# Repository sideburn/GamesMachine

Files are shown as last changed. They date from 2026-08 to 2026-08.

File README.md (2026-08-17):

# Games Machine

KiCad recreation of **"Games Machine — a programmed random number generator"** by D. Burn,
*Practical Electronics*, December 1976 (pp. 969–975). PCB by Sideburn Studios.

A TTL-logic random number generator with four selectable modes:

| Mode | Range | Zero behaviour |
|---|---|---|
| Random | 0–99 | `00` allowed |
| Roulette | 0–36 | `00` allowed |
| Pools | 1–59 | single zero allowed, `00` blocked |
| Dice | 1–6 per digit | no zero in either digit |

Randomness comes from an avalanche-noise transistor (TR1) feeding a two-stage amplifier
(TR2, TR3), squared by a 7413 Schmitt trigger, and gated into a pair of 7490 decade counters
while a 2N2646 UJT relaxation oscillator (TR4) free-runs at 3–4 s. Because the operator's
press and the oscillator phase are uncorrelated, the stopping point is unpredictable. Game
ranges and the zero-detector restart logic come from a diode-resistor matrix (D5–D20) read
through an interlocked pushbutton bank (S1, S3–S6).

## Status

**Rev 1.0** — fabricated 2026-07-09, built and fully bench-tested. All four game modes verified
working against the behaviour described in the original article. Three defects were found and
worked around on the physical board (see below).

**Rev 2.0** — all fixes applied to the KiCad source, DRC clean (0 violations, 0 unconnected),
gerbers and drill files regenerated. Ready to order; not yet fabricated.

### Fixes applied for rev 2.0

| # | Issue | Resolution |
|---|---|---|
| 1 | `LOGIC_0` was a floating net, never tied to ground — board freezes at `99` | Merged into `GND` |
| 2 | Diode silkscreen band marked the anode, so all 17 diodes fitted backwards to the print | Symbol pin numbers swapped, diodes rotated 180° |
| 3 | UNITS/TENS displays placed in reverse reading order — digits read transposed | Placements exchanged |
| 4 | 2N2926 symbol declared E-B-C; the real part is E-C-B, so TR1–TR3 needed crossed leads | Pin numbers corrected |
| 5 | TR4 (2N2646) footprint mapping suspected wrong | Verified correct as drawn — no change |

Full detail, including what was deliberately left alone, is in `Docs/Rev2_Board_Fixes.md`.

## Notes for anyone building one

- **Identify a UJT's leads by measurement, never from a pinout diagram.** Ohms-mode resistive
  pair = the two bases, the leftover lead = emitter; the can-to-lead short then separates B1
  from B2. Two of the three 2N2646s sourced for this build were counterfeit or dead, and one
  passed a static meter test while being unable to fire under real operating bias.
- TR4 wants rotating roughly 10° clockwise of the silkscreen tab mark when fitting — the TO-18
  leads sit on a circle and don't land dead-on the pad angles.

## Repository contents

- `GamesMachine.kicad_sch` / `.kicad_pcb` / `.kicad_pro` — the KiCad project
- `GamesMachine.kicad_sym` — project-local symbol library (custom parts)
- `GamesMachine.stl` — 3D case/board model
- `Gerbers/` — fabrication output, regenerated for rev 2.0
- `Docs/PartsList.md` — full parts list with sourcing notes
- `Docs/BOM.csv` — machine-readable BOM exported from the schematic
- `Docs/BringUp_TestPlan.md` — staged bring-up and test procedure
- `Docs/GameMode_Jumper_Reference.md` — switch/jumper configuration per game mode
- `Docs/Rev2_Board_Fixes.md` — defect record and how each was resolved

The first commit is the rev 1.0 project exactly as fabricated, so the whole set of fixes can be
read as a diff against the board that was actually built.

## Original source

*Practical Electronics*, Vol. 12 No. 12, December 1976. Article by D. Burn, PhD.
The magazine scan is not redistributed here.

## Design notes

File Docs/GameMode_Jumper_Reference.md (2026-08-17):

# Games Machine — Game Mode Jumper Reference

Bench-test jumper configurations for each game mode, confirmed working 2026-08-17. These
simulate the real interlocked pushbutton switches (S3-S6) until the physical switch loom is
wired in.

General pattern for every S3/S4/S5/S6 pole: pin 1 = input from previous switch in the chain,
pin 2 = "released" (pass-through to next switch), pin 3 = "pressed" (this mode's own decode
network or ground). Only one mode's switch should be "pressed" (1&3) at a time — everything
else stays in pass-through (1&2) or fully open, matching the real hardware's mechanical
interlock (pressing one button releases whichever was previously pressed).

S1 (Play) is a separate 2-pole momentary button, not part of this chain — pressed = pin 1&2
connected.

**On "all others open" below:** with real physical switches, no pole is ever truly
disconnected — every unpressed switch mechanically rests at 1&2 (released), every pressed
one sits at 1&3. "Open" in the tables below is a bench-jumper shortcut for switches outside
the active chain for that mode; jumpering them to 1&2 instead is equally correct and in fact
more accurately mirrors how the finished hardware behaves.

---

## Random — range 0–99

| Switch | Position |
|---|---|
| S3a, S3b | 1&3 closed |
| S5c, S6d | 1&2 closed |

All others open.

## Roulette — range 0–36

| Switch | Position |
|---|---|
| S3a, S3b | 1&2 closed |
| S4a, S4b | 1&3 closed |
| S5c | 1&2 closed |
| S6d | 1&2 closed |

All others open.

## Pools — range 1–59

| Switch | Position |
|---|---|
| S3a, S3b | 1&2 |
| S4a, S4b | 1&2 |
| S5a, S5b, S5c | 1&3 |
| S6c | 1&2 |

All others open.

## Dice — 1–6 each digit

| Switch | Position |
|---|---|
| S3a, S3b | 1&2 |
| S4a, S4b | 1&2 |
| S5a, S5b, S5c | 1&2 |
| S6a, S6b, S6c, S6d | 1&3 |

---

## Zero-digit behavior by mode

- **Random**: 00 fully allowed (confirmed stable, non-blanking stop).
- **Roulette**: 00 fully allowed (per article: "a selection of 00 is perfectly acceptable").
- **Pools**: single zero in either digit allowed (e.g. 02, 20); double-zero (00) blocked,
  triggers blank-and-respin.
- **Dice**: no zero allowed in either digit — cannot stop while either digit shows 0.

Source: original article, *Practical Electronics*, Dec 1976, "Random Number Gamesmachine"
by D. Burn, p.972 (Zero Detector section) and p.971-972 (circuit description).

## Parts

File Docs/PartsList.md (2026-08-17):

# Games Machine — parts list

Generated from the rev 2.0 schematic. Quantities are for one board.

Resistors are ¼ W carbon film throughout; the footprints are 10.16 mm pitch axial.

## On-board parts

### Resistors

| Refs | Value | Qty | Function |
|---|---|---|---|
| R1 | 47 kΩ | 1 | Noise generator, TR1 emitter feed |
| R2 | 4.7 kΩ | 1 | TR2 collector load |
| R3 | 100 kΩ | 1 | TR3 collector-base bias |
| R4, R5 | 2.2 kΩ | 2 | TR3 collector load, noise output |
| R6 | 150 kΩ | 1 | UJT clock timing (with C4) |
| R7 | 220 Ω | 1 | UJT clock output |
| R8, R9, R10 | 4.7 kΩ | 3 | Open-collector pull-ups for IC11 |
| R11–R24 | 270 Ω | 14 | Display segment current limiting |
| R25 | 1 kΩ | 1 | `LOGIC_1` pull-up |
| R26–R30 | 1 kΩ | 5 | Game-mode decode pull-ups |

### Capacitors

| Refs | Value | Qty | Notes |
|---|---|---|---|
| C1, C2, C4 | 10 µF | 3 | Article specifies 16 V tantalum; modern electrolytics work fine. Polarity: **+ toward the higher-voltage node** |
| C3 | 0.1 µF | 1 | Ceramic disc |

### Semiconductors

| Refs | Part | Qty | Notes |
|---|---|---|---|
| TR1–TR3 | 2N2926 | 3 | Noise generator. Real pinout is **E-C-B** |
| TR4 | 2N2646 | 1 | UJT clock oscillator. Article also allows TIS43 |
| D5–D20 | 1N914 | 16 | Game-mode decode matrix |
| Z1 | 1N4733A (5.1 V) | 1 | Rail clamp |
| IC1 | 7413 | 1 | Dual 4-input Schmitt NAND — squares the noise, gates it |
| IC2 | 7472 | 1 | JK flip-flop — start/stop bistable |
| IC3, IC4 | 7490 | 2 | Decade counters (tens, units) |
| IC5, IC6 | 7447 | 2 | BCD to 7-segment decoders |
| IC9 | 7425 | 1 | Dual 4-input NOR — zero detector |
| IC10 | 7480 | 1 | Gated full adder, used as switchable AND/OR |
| IC11 | 7412 | 1 | Triple 3-input open-collector NAND — restart logic |

### Connectors and other

| Refs | Part | Qty | Notes |
|---|---|---|---|
| PWR1 | JST PH 3-pin vertical | 1 | +17 V, +5 V, GND from the supply |
| S1 | JST PH 2-pin vertical | 1 | Play button |
| S3a–S6d | JST PH 3-pin vertical | 11 | Game-mode switch bank, one per pole |
| F1 | 0.5 A resettable PTC | 1 | Radial, 5 mm |
| TENS1, UNITS1 | 14-pin DIP socket | 2 | The DL707 displays plug in here |

IC sockets are strongly recommended for all of IC1–IC11 — most of these are obsolete parts and
you'll want to be able to swap them while testing.

## Off-board parts

| Part | Qty | Notes |
|---|---|---|
| DL707 7-segment display, common anode | 2 | 0.3 in red. Plug into TENS1/UNITS1 |
| Interlocked pushbutton bank | 1 | 5 latching buttons plus one Play. Article used a Doram 8-switch frame with latching bar and return spring; pressing one button releases the others |
| Power supply | 1 | +17 V and +5 V. See below |

### Power

The article's own supply (its Fig. 3) is a mains transformer, bridge rectifier, 2200 µF filter
and a µA7805 regulator, giving ~17 V unregulated plus a regulated 5 V rail. None of that lives
on this board — it arrives through PWR1.

The simplest modern equivalent is a single regulated **18 V, 1 A universal-input (100–240 V)
switching adapter**, with the 5 V rail derived from it. Typical measured draw is around 120 mA
on the 5 V rail with everything populated.

## Sourcing notes

Most of the logic is obsolete but still easy to find from surplus dealers. Two parts deserve
attention.

**2N2646 (TR4)** — this is the part most likely to waste your time. Of three obtained for this
build, one was a relabelled PNP bipolar (not a UJT at all), one was genuine but so degraded by
age that it passed every static meter test while being unable to fire under real operating bias,
and one was good. Buy from a dealer with verifiable vintage stock, buy spares, and **test each
one before fitting**:

1. Ohms mode: the two leads showing a resistive 4.7–9 kΩ both ways are the bases; the leftover
   lead is the emitter.
2. The base that reads ~0 Ω to the metal can is B2.
3. Diode mode from the emitter: a normal forward drop into each base, open in reverse.

A genuine part that passes this can still be too aged to oscillate, so the real test is fitting
it and looking for the sawtooth at the emitter. **2N6027** programmable UJTs are still in
production and can substitute, but need a gate-bias divider added and R6 changed to ~330 kΩ.

**2N2926 (TR1–TR3)** — real pinout is **E-C-B**, which trips up a lot of pinout diagrams online.
Rev 2.0 of this board is drawn for the correct order, so parts drop straight in.

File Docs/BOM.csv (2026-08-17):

Refs | Value | Footprint | Qty
C1,C2,C4 | 10uF | Capacitor_THT:CP_Radial_D5.0mm_P2.50mm | 3
C3 | 0.1uF | Capacitor_THT:C_Disc_D5.0mm_W2.5mm_P2.50mm | 1
D5-D20 | 1N914 | Diode_THT:D_DO-35_SOD27_P7.62mm_Horizontal | 16
F1 | PTC_0.5A | Capacitor_THT:C_Disc_D5.0mm_W2.5mm_P5.00mm | 1
IC1 | 7413 | Package_DIP:DIP-14_W7.62mm | 1
IC2 | 7472 | Package_DIP:DIP-14_W7.62mm | 1
IC3,IC4 | 7490 | Package_DIP:DIP-14_W7.62mm | 2
IC5,IC6 | 7447 | Package_DIP:DIP-16_W7.62mm | 2
IC9 | 7425 | Package_DIP:DIP-14_W7.62mm | 1
IC10 | 7480 | Package_DIP:DIP-14_W7.62mm | 1
IC11 | 7412 | Package_DIP:DIP-14_W7.62mm | 1
PWR1 | POWER_JST_PH3 | Connector_JST:JST_PH_B3B-PH-K_1x03_P2.00mm_Vertical | 1
R1 | 47k | Resistor_THT:R_Axial_DIN0207_L6.3mm_D2.5mm_P10.16mm_Horizontal | 1
R2,R8-R10 | 4.7k | Resistor_THT:R_Axial_DIN0207_L6.3mm_D2.5mm_P10.16mm_Horizontal | 4
R3 | 100k | Resistor_THT:R_Axial_DIN0207_L6.3mm_D2.5mm_P10.16mm_Horizontal | 1
R4,R5 | 2.2k | Resistor_THT:R_Axial_DIN0207_L6.3mm_D2.5mm_P10.16mm_Horizontal | 2
R6 | 150k | Resistor_THT:R_Axial_DIN0207_L6.3mm_D2.5mm_P10.16mm_Horizontal | 1
R7 | 220 | Resistor_THT:R_Axial_DIN0207_L6.3mm_D2.5mm_P10.16mm_Horizontal | 1
R11-R24 | 270 | Resistor_THT:R_Axial_DIN0207_L6.3mm_D2.5mm_P10.16mm_Horizontal | 14
R25-R30 | 1k | Resistor_THT:R_Axial_DIN0207_L6.3mm_D2.5mm_P10.16mm_Horizontal | 6
S1 | SPDT | Connector_JST:JST_PH_B2B-PH-K_1x02_P2.00mm_Vertical | 1
S3a1,S3b1,S4a1,S4b1,S5a1,S5b1,S5c1,S6a1,S6b1,S6c1,S6d1 | SPDT | Connector_JST:JST_PH_B3B-PH-K_1x03_P2.00mm_Vertical | 11
TENS1 | TENS_DISP_SOCKET | Package_DIP:DIP-14_W7.62mm | 1
TR1-TR3 | 2N2926 | Package_TO_SOT_THT:TO-92_Inline | 3
TR4 | 2N2646 | Package_TO_SOT_THT:TO-18-3 | 1
UNITS1 | UNITS_DISP_SOCKET | Package_DIP:DIP-14_W7.62mm | 1
Z1 | 1N4733A_5.1V | Diode_THT:D_DO-41_SOD81_P10.16mm_Horizontal | 1

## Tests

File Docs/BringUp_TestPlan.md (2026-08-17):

# Games Machine — Board Bring-Up & Sectional Test Plan

Random Numbers Game Machine, Sideburn Studios
Source design: "Games Machine — a programmed random number generator", D. Burn,
*Practical Electronics*, December 1976, pp. 969–975.

Published reference copy: https://claude.ai/code/artifact/c53d6dda-828d-4b43-869a-0b2889a355c7

---

> ## ⚠ Check your board revision first
>
> This plan was written against **rev 1.0**. The two workarounds under "Before you assemble"
> apply **only to rev 1.0** — both defects are fixed in the rev 2.0 design.
>
> **On a rev 2.0 board, skip findings 1 and 2 entirely:**
> - Do **not** fit the `LOGIC_0` → ground bodge wire. That net is part of `GND` now.
> - Do **not** fit the diodes opposite the silkscreen. The band marks the **cathode** correctly
>   on rev 2.0, so "backwards to the print" would put all 17 diodes in the wrong way round.
>
> Everything from "Staged bring-up" onward applies to both revisions — the circuit itself is
> unchanged. The schematic title block gives the revision.

---

## Before you assemble — three findings *(rev 1.0 only — see warning above)*

### 1. CRITICAL — `LOGIC_0` is never connected to ground *(rev 1.0 only)*

`GND` and `LOGIC_0` are two separate nets on this board. In the 1976 schematic the "0" symbol
simply *is* 0 V, but here `LOGIC_0` was drawn as its own label and never tied down. It has
38 routed track segments and 12 pads, and **no source of any kind** — no connector pin, no
resistor, no link to the ground pour.

Pads on `LOGIC_0`: IC2 pins 3, 4, 5 (J1–J3) · IC3 pins 6, 7 · IC4 pins 6, 7 (set-to-nine) ·
S3a pin 3 · S3b pin 3 · S5a pin 3 · S6c pin 2 · S6d pin 2.

Floating TTL inputs read as logic 1, so as built:

- Both 7490s permanently forced to nine → frozen `99` on the display, never counts.
- IC2 J-inputs high → the bistable toggles instead of resetting; start/stop unreliable.
- Random and pools switch positions cannot release the counter resets.

**Fix:** one short insulated wire on the solder side, **IC3 pin 7 → IC3 pin 10**. That is one
`LOGIC_0` pad to one `GND` pad on the same package. Afterwards confirm continuity at a far
point such as IC2 pin 3. Correct the schematic before any future board order.

### 2. Diode silkscreen band is on the anode end

The project's cached `Device:D` symbol has **pin 1 = anode, pin 2 = cathode**. Stock KiCad has
it the other way round, and the stock THT diode footprints put the printed cathode band at the
**pad 1** end. So the silk band sits at the end the netlist treats as the anode — on all
sixteen 1N914s and on Z1.

The netlist intent is electrically correct (diode-AND gates with anode on the pulled-up node;
Z1 cathode to +5V). Only the printed marking misleads.

**Verify on the bare board:** the Z1 pad at the silkscreen band end should show continuity to
`GND`, the far pad to `+5V`. If so, fit every diode with its **body band pointing away from the
printed band**. Z1 backwards puts a forward diode across the 5 V rail.

### 3. No decoupling, and a tight fuse

- **No supply decoupling anywhere on the digital section.** C1–C4 all belong to the analogue
  block. Add 100 nF ceramic across pins 7/14 of each DIP (8/16 on the 7447s) and a 100 µF bulk
  cap at `PWR`. Much easier during assembly than after.
- **F1** is a 0.5 A PTC in series with the whole 5 V rail; worst-case draw is near 600 mA.
- **Z1** is a 1N4733A 5.1 V zener directly across a 5.0 V rail — close enough to its knee to
  conduct continuously. Consider a 1N4734A (5.6 V) or omit.

---

## Bench setup

`PWR` is a 3-pin JST PH at the right-hand edge. No on-board regulator — both rails come in
externally.

| Pin | Net | Set to | Current limit | Feeds |
|-----|-----|---|---|---|
| 1 | GND | 0 V common | — | Ground pour, all IC ground pins |
| 2 | +5V_IN | 5.00 V | start 100 mA | Through F1 to all logic and both displays |
| 3 | +17V | 17.0 V | 50 mA | Only R2, R4, R6, TR4 — analogue section |

**Sequencing:** bring 5 V up first, then *ramp* 17 V. Power 17 V down first, 5 V last. The
noise output couples through C3 (0.1 µF) straight onto IC1 pin 5, a TTL input with no positive
clamp; switching 17 V in abruptly couples that step into the input.

If the supply's outputs are independent, tie both negatives together at the board.

**Two changes worth making for bench work:**

- Link out F1 and let the bench current limit protect instead — faster, adjustable, and it
  removes the PTC volt-drop from rail measurements.
- Socket every IC. The whole plan depends on populating the board progressively.

---

## Stages

Ordered so each stage only powers what the previous one proved. The display end is proved first
and you work backwards toward the analogue front end.

### Stage 0 — Bare board, before soldering

| Check | Probe | Expect | Meaning |
|---|---|---|---|
| Ground integrity | PWR pin 1 → IC1 pin 7, IC5 pin 8 | < 1 Ω | Pour reaches every package |
| **LOGIC_0 defect** | IC3 pin 7 → PWR pin 1 | **OPEN** | Confirms the defect |
| LOGIC_1 rail | IC1 pin 1 → R25 pad 2 | < 1 Ω | Tie-high net routed |
| Rail short | +5V pad → GND | open | No fabrication short |
| **Diode marking** | Z1 band-end pad → GND | continuity | Band is on the anode — fit diodes reversed to print |
| 17 V rail | PWR pin 3 → R2, R4, R6 | < 1 Ω | Routed, and isolated from +5V |

### Stage 1 — Power section and the ground fix

Fit: PWR, F1 (or link), Z1, R25, the LOGIC_0 wire link, all IC sockets, decoupling caps.
Leave every socket **empty**. 5.00 V, limit 100 mA.

| Measure | Expect | If it differs |
|---|---|---|
| Total 5 V current | < 5 mA | Tens of mA → Z1 conducting; swap for 1N4734A or omit |
| Rail at each socket Vcc | 5.00 V | Sag points at F1 or a routing fault |
| LOGIC_1 at IC1 pin 1 | ≈ 5.0 V | 0 V → R25 open or misfitted |
| LOGIC_0 at IC2 pin 3 | 0.00 V | Link did not take, or net not fully routed |
| Z1 temperature | cold | Warm → continuous conduction |

**Stop if** 5 V current exceeds a few mA with no ICs fitted.

### Stage 2 — The 17 V rail

Sockets still empty. With 5 V already up, **ramp** the second output slowly to 17 V, limit
50 mA. Confirm 17 V at the top of R2, R4, R6, and **0 V at IC1 pin 5** (held down by R5).

### Stage 3 — Noise generator and clock

Fit: TR1–TR3, TR4, R1–R7, C1–C4. Logic sockets still empty.

Orientation notes:
- TR1–TR3 = 2N2926, TO-92, pad 1 = E, 2 = B, 3 = C.
- TR4 = 2N2646 UJT in **TO-18 metal can** (different footprint), pad 1 = E, 2 = B1, 3 = B2.
- C1, C2, C4 are correctly silk-marked (unlike the diodes): **+** is the pad 1 end.
- **TR1's collector is deliberately unconnected.** The noise comes from its reverse-biased
  base-emitter junction avalanching. Do not "fix" it.

| Test | Where | Pass criterion |
|---|---|---|
| Clock running | across R7 (220 Ω) | A pulse every ~3–4 s, visible on a DMM |
| Noise present | NOISE_OUT / IC1 pin 5 | Random noise you **cannot trigger the timebase on**. A stable trace means the noise source is *not* working. |
| DC sanity | NOISE_OUT to GND | Low DC level (R5 holds it down). Near 17 V → C3 leaky or misfitted. |

No noise usually means this particular 2N2926 will not avalanche at 17 V — breakdown scatters
between devices. Try another transistor.

**Stop if** NOISE_OUT sits at a high DC level — fitting IC1 with 17 V on a TTL input destroys it.

### Stage 4 — Displays and decoders, via the lamp test

Fit: IC5, IC6, R11–R24, both DL707s. **5 V only, 17 V off.** Raise the 5 V limit to ~700 mA.

The 7447 lamp-test input is on **pin 3** of both decoders. **Ground pin 3 and every segment
lights**, showing `8`. That verifies the decoder, all seven segment resistors, the socket wiring
and the display itself, per digit, with no counter or clock involved.

With both digits showing `8` you are at worst-case display current — **this is also your F1
margin measurement**. Note the total.

Blanking (pin 4 on both 7447s) comes from IC2, which is not fitted, so it floats high and
blanking is inactive. Tack a temporary 1 kΩ from that net to +5 V so it is held rather than
floating.

Displays are confirmed **DL707 / MB101 common anode**; the board correctly ties socket pins 3
and 14 to +5 V. Socket pin 9 (third common anode) is unconnected — harmless, but strapping it
to pin 3 shares segment current across three pins instead of two.

### Stage 5 — Counters, on an injected clock

Fit: IC3, IC4, IC11, R8–R10.

With no switch panel wired the reset lines float high and hold both counters cleared (`00`).
To emulate **random numbers** mode on the bench, ground **S3a pin 1** and **S3b pin 1**
(the `IC4_R0` and `IC3_R0` connector pins). Both counters can then run 0–99.

Inject **1–2 Hz** at **IC4 pin 14** (units counter clock). A debounced pushbutton works for
single-stepping.

**Expect a strange counting sequence — it is correct.** The tens digit is clocked from the
units **C** output inverted by IC11c, so the tens digit advances each time the units digit
passes 4. The article does this deliberately: in dice mode the units counter resets at 6, so D
never toggles and a conventional carry would never fire. No numbers are lost.

**Stop if** you see a frozen `99` — that is the signature of the `LOGIC_0` defect.

### Stage 6 — Gate and bistable

Fit: IC1, IC2.

Keep the UJT clock out of circuit so you can step by hand: **lift R7**, fit a temporary 1 kΩ
from IC1 pin 9 to +5 V, and a momentary pushbutton from pin 9 to ground. Press-and-release
generates the falling edge that clocks IC2. Keep injecting the slow clock at IC4 pin 14.

**The net names lie — the wiring is right.** The custom 7472 symbol has its labels swapped
against the real SN7472 (clear on pin 2, preset on pin 13, Q on pin 8, Q̄ on pin 6). Both pairs
are inverted, so they cancel and the board is wired exactly as the article specifies. But the
net named `IC2_Q` is physically Q̄, and `IC2_QBAR` is physically Q.

| Action | Expect | Because |
|---|---|---|
| At rest | Display lit and static | Q̄ high, blanking inactive; gate closed |
| Press Play (S1 pin 1 to ground) | Display **blanks**, counting starts | Preset asserted: Q high opens the gate, Q̄ low blanks the 7447s |
| Release Play, pulse manual clock | Counting stops, number appears | J=0, K=1 resets on the clock edge |

Then restore R7 and let the real 3–4 s UJT clock take over.

### Stage 7 — Game modes and zero detector

Fit: D5–D20, R26–R30, IC9, IC10, the switch loom. Keep the injected slow clock.

| Mode | Range | Expected behaviour |
|---|---|---|
| **No game selected** | — | Holds `00`, will not count. Designed behaviour; confirm first. |
| Random | 00–99 | Full cycle in the odd sequence; stoppable on any count including `00` |
| Roulette | 0–36 | Reaches 33 via `36 30 31 32`, resets to `04`, continues `05 06 07`… |
| Pools | 1–59 | `…58 59 50 51 52 53 04 05…`. Stops on a single zero, **ignores stop when both digits are zero** |
| Dice | 1–6 each | Neither digit exceeds 6; **cannot be stopped while either digit shows zero** |

The last two rows are the zero detector working: IC9 spots an all-zero digit, IC10 combines the
two digits as AND or OR depending on S6c, IC11b restarts the count.

Finally remove every temporary link — blanking pull-up, manual clock switch, grounded reset
pins, injected clock.

---

## Reference

### Current budget (approximate, typical standard TTL)

| Load | Typical | Note |
|---|---|---|
| Nine TTL packages | ≈ 290 mA | The two 7447s dominate at ~64 mA each |
| Both digits showing `88` | ≈ 155 mA | 14 segments × ~11 mA through 270 Ω |
| Typical running total | ≈ 400 mA | Average digit lights about five segments |
| **Worst case** | **≈ 580 mA** | Past F1's 0.5 A hold current |
| 17 V rail | < 15 mA | Only R2, R4, R6 |

### Symptom → cause

| Symptom | Most likely cause |
|---|---|
| Frozen `99`, never counts | `LOGIC_0` floating — set-to-nine inputs read high |
| Frozen `00`, never counts | No game selected, or a reset line stuck high — switch latching or loom |
| 5 V rail sags under load | F1 near its hold current — link it out for bench work |
| Rail collapses at power-on | Z1 fitted backwards |
| Noise trace triggers cleanly | Noise source dead; TR1 not avalanching. Try another 2N2926. |
| Erratic counts, random restarts | Missing decoupling |
| Tens digit advances "too early" | Correct behaviour — carry is the inverted units C output |
| A game mode never resets | Diodes fitted to the silkscreen band instead of against it |

### Open items for the switch loom

- The second red pushbutton on the original panel is still unidentified (annotated `?` in the
  Fig. 5 overlay on `IMG_5886.jpg`).
- S1's third contact has no confirmed use; the board only needs two.
- Dashed lines in the magazine drawing are **mechanical ganging only**, not electrical —
  S3a/S3b etc. are poles of a single interlocked pushbutton.

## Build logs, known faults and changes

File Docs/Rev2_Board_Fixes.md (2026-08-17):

# Games Machine — rev 2.0 board fixes

Defects found during rev 1.0 bring-up (2026-08-08 → 2026-08-16) and how each was resolved in
the KiCad source (2026-08-16 → 2026-08-17).

**Status: all fixes applied. DRC clean — 0 violations, 0 unconnected. Gerbers and drill files
regenerated. Board is ready to order.**

---

## 1. `LOGIC_0` never tied to ground — FIXED

`LOGIC_0` was its own net with no connection to `GND` anywhere: 38 routed segments across 12
pads (IC2 pins 3/4/5, IC3 and IC4 pins 6/7, S3a/S3b/S5a pin 3, S6c/S6d pin 2) and nothing
driving it. Floating TTL inputs read high, so both 7490s sat permanently forced to nine — the
symptom on an unfixed board is a frozen `99` that never counts. Rev 1.0 workaround was a bodge
wire from IC3 pin 7 to IC3 pin 10.

**Fix:** renamed all 12 `LOGIC_0` labels to `GND`, merging the nets, then updated and re-routed
the PCB. The bodge wire is not needed on rev 2 — those pads are genuinely part of the ground
net now, so the pour reaches them.

## 2. Diode silkscreen band marked the anode — FIXED

The schematic's *cached copy* of `Device:D` had pin 1 = anode, while the stock footprint
(`Diode_THT:D_DO-35_SOD27_P7.62mm_Horizontal`) correctly places the silkscreen cathode band at
pad 1. The footprint was never wrong — only the cached symbol had drifted from the stock
library. Result: the printed band marked the **anode** end on all of D5–D20 and Z1, so every
diode had to be fitted opposite the silkscreen.

**Fix:** swapped the pin *numbers* in the cached symbol (the "A" position is now 2, the "K"
position now 1), leaving names, graphics and wiring untouched. KiCad binds wires by coordinate
rather than pin number, so this corrected all 17 diodes in one edit. Each diode footprint was
then rotated 180° so pad 1 sits where pad 2 was — this both restores the original routing
geometry and carries the band to the cathode end.

Verified by netlist: Z1 now reads pin 1 → `/+5V`, pin 2 → `/GND`; D11 pin 1 → `/IC3_QA`,
pin 2 → `/S4A_ROULETTE37` — both reversed from rev 1.0, electrical intent unchanged. Confirmed
visually in the 3D view.

## 3. Display digits in reverse reading order — FIXED

UNITS sat on the left (x=149) and TENS on the right (x=164), so every result read with its
digits transposed — the board showed `41` for the value 14. Wiring and silkscreen labels were
self-consistent, so this was purely placement, but it convincingly masqueraded as a Roulette
range failure during bring-up.

**Fix:** exchanged the two placements — TENS1 now at x=149 (left), UNITS1 at x=164 (right).
Identical DIP-14 footprints at the same Y with no rotation, so a straight swap; each display
keeps its own segment nets. Display area re-routed.

Segment resistor banks deliberately left alone: R11–R17 (tens) and R18–R24 (units) are
horizontal rows already spanning the full width above both displays, so only the routing
between them changed.

## 4. 2N2926 pin order — FIXED (TR1, TR2, TR3)

The project-local symbol declared E-B-C, but the real 2N2926 is **E-C-B** (per the Central
Semiconductor datasheet). All three had to be fitted with leads 2 and 3 crossed on rev 1.0.

**Fix:** swapped the B and C pin numbers in both `GamesMachine.kicad_sym` and the schematic's
cached copy. Netlist now reads pad 1 = E, pad 2 = C, pad 3 = B, so the part drops straight in.
PCB updated and re-routed.

## 5. TR4 (2N2646 UJT) footprint — NO CHANGE NEEDED

Checked against the 3D view on 2026-08-17: the pin mapping is correct as drawn and TR4 drops in
fine. The part just wants rotating roughly 10° clockwise from the silkscreen tab mark when
fitting, because the TO-18 leads sit on a circle and don't line up dead-on with the pad angles.
A fitting nuance, not a defect.

Identify a UJT's leads by **measurement**, never from a pinout diagram — ohms-mode resistive
pair = the two bases, leftover lead = emitter, then the can-to-lead short distinguishes B1 from
B2. Two of the three 2N2646s sourced during rev 1.0 bring-up were counterfeit or dead, and one
passed a static meter test while being unable to fire under real bias.

---

## Housekeeping done alongside

- Two stitching vias added at IC3 pad 7 and S5a1 pad 3, each with a short stub track, clearing
  the last two `starved_thermal` errors. Both are former `LOGIC_0` pads that reached only an
  isolated island of the top-layer pour.
- Gerbers and drill files regenerated from the current board (the folder previously held rev 1.0
  output).

## Considered and deliberately not changed

- **Decoupling capacitors** on the digital section — the board runs fine without them; not worth
  the layout churn.
- **F1** (0.5 A PTC) — the paper worst case is around 580 mA, but the built board runs correctly
  on it, so it stays as is.
- **Z1** (1N4733A, 5.1 V) sits close to its knee on a 5.0 V rail. Measured 4.7–4.8 V in practice
  with Z1 fitted, so it isn't conducting — fine as built. A 5.6 V part would give more margin if
  ever revisited.
- The custom **7472** symbol has its PRE/CLR and Q/Q̄ label pairs swapped versus the real SN7472.
  The two inversions cancel so the board is wired correctly, but net `IC2_Q` is physically Q̄ and
  `IC2_QBAR` is physically Q — confusing when probing. Worth relabelling if the symbol is ever
  touched again.

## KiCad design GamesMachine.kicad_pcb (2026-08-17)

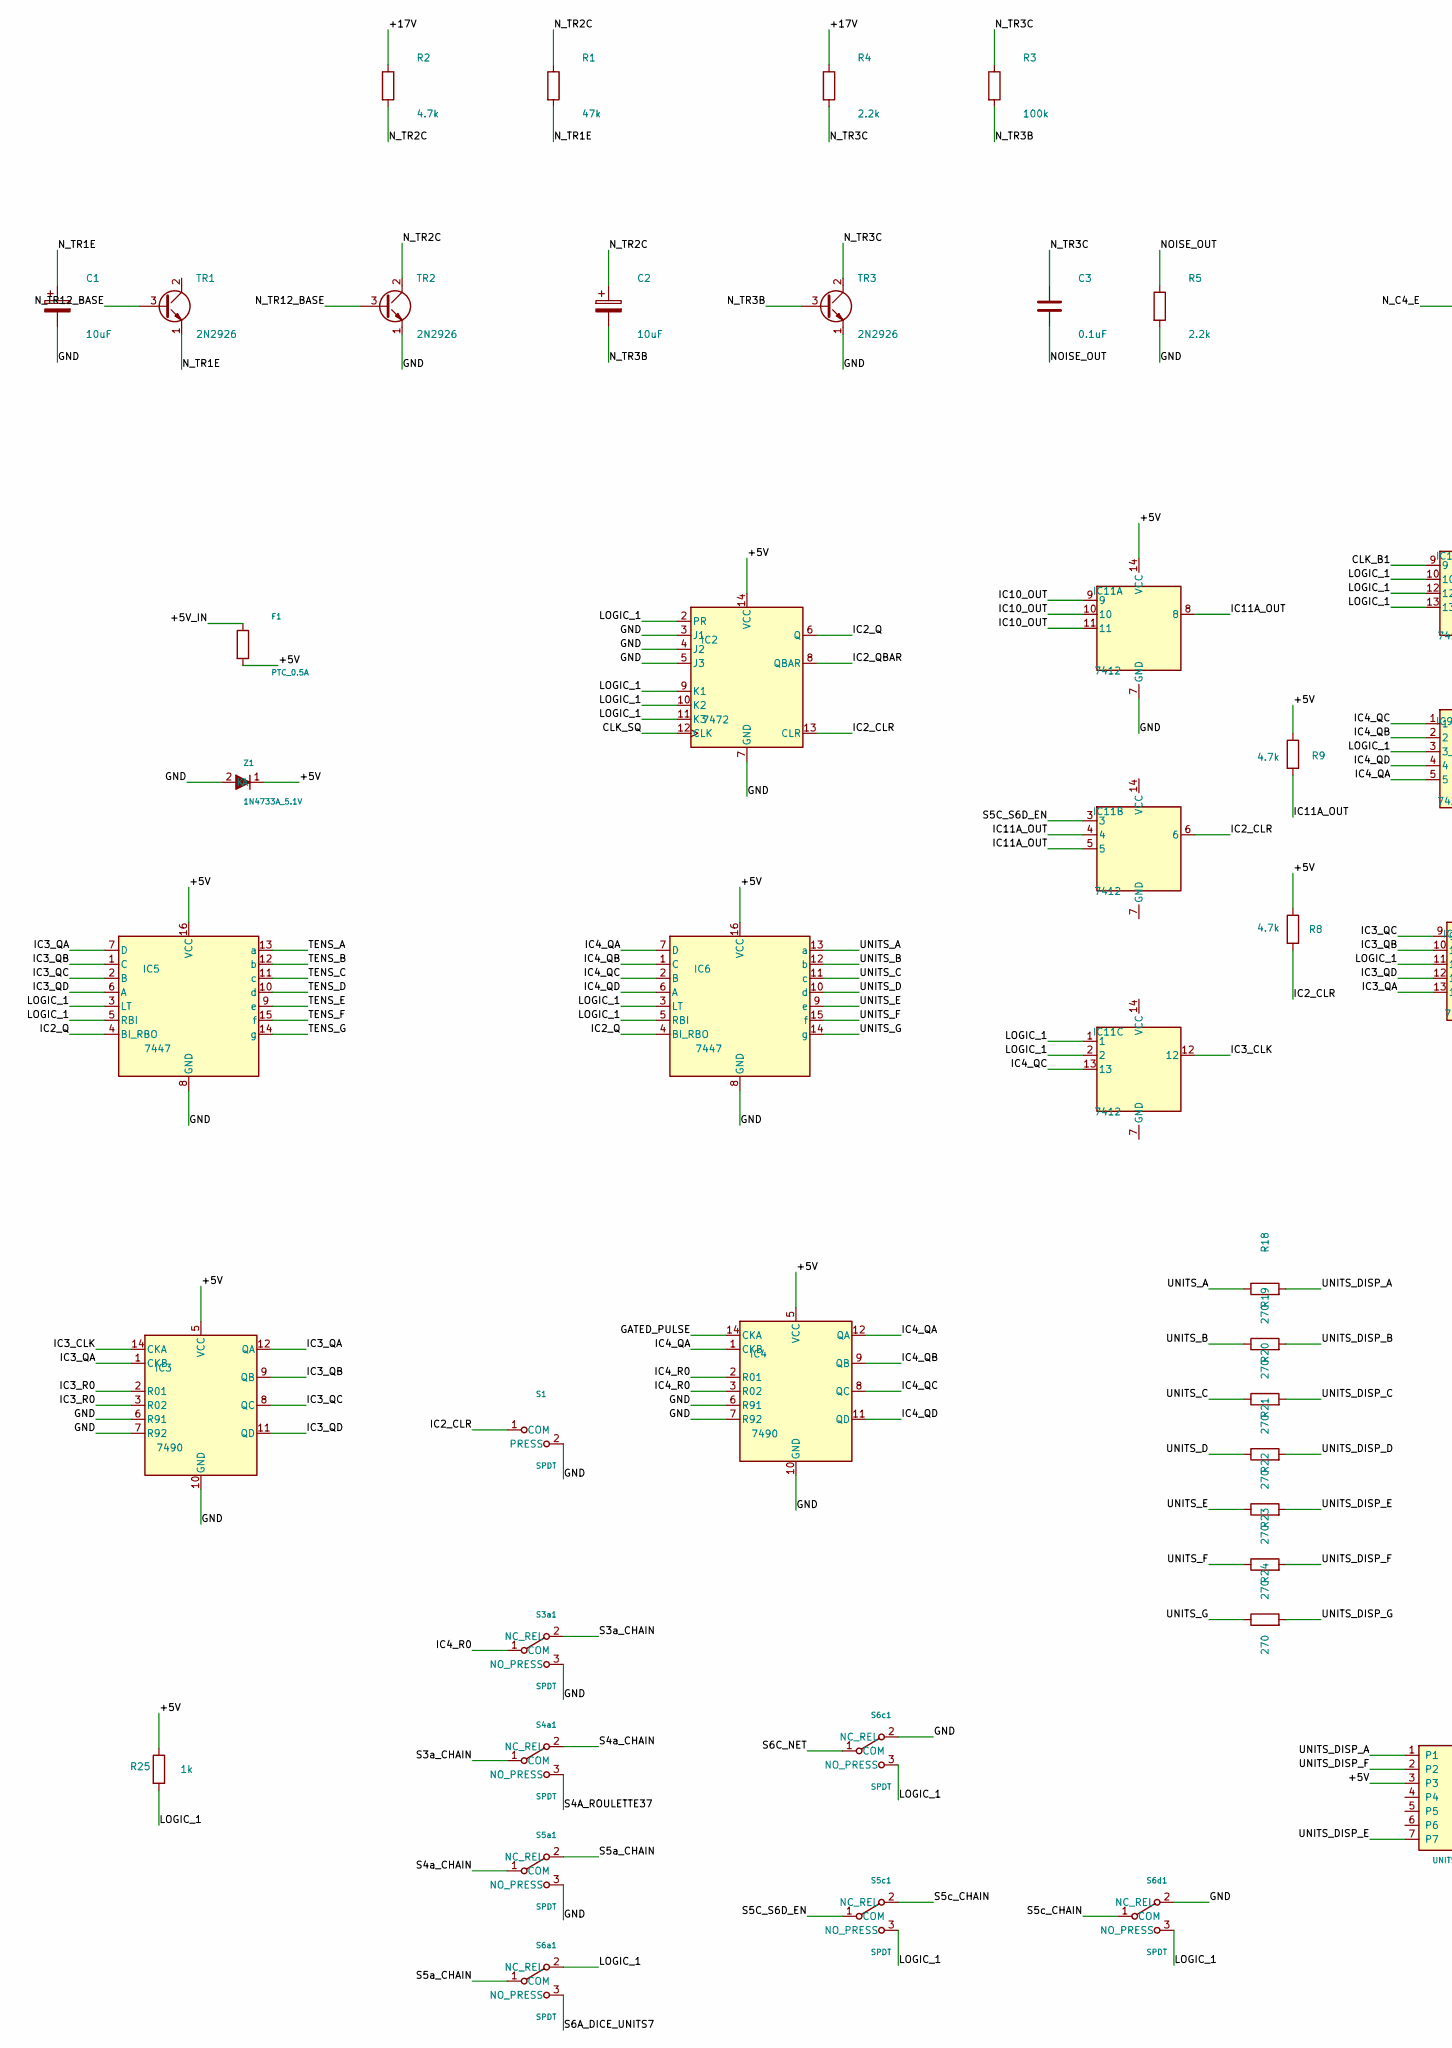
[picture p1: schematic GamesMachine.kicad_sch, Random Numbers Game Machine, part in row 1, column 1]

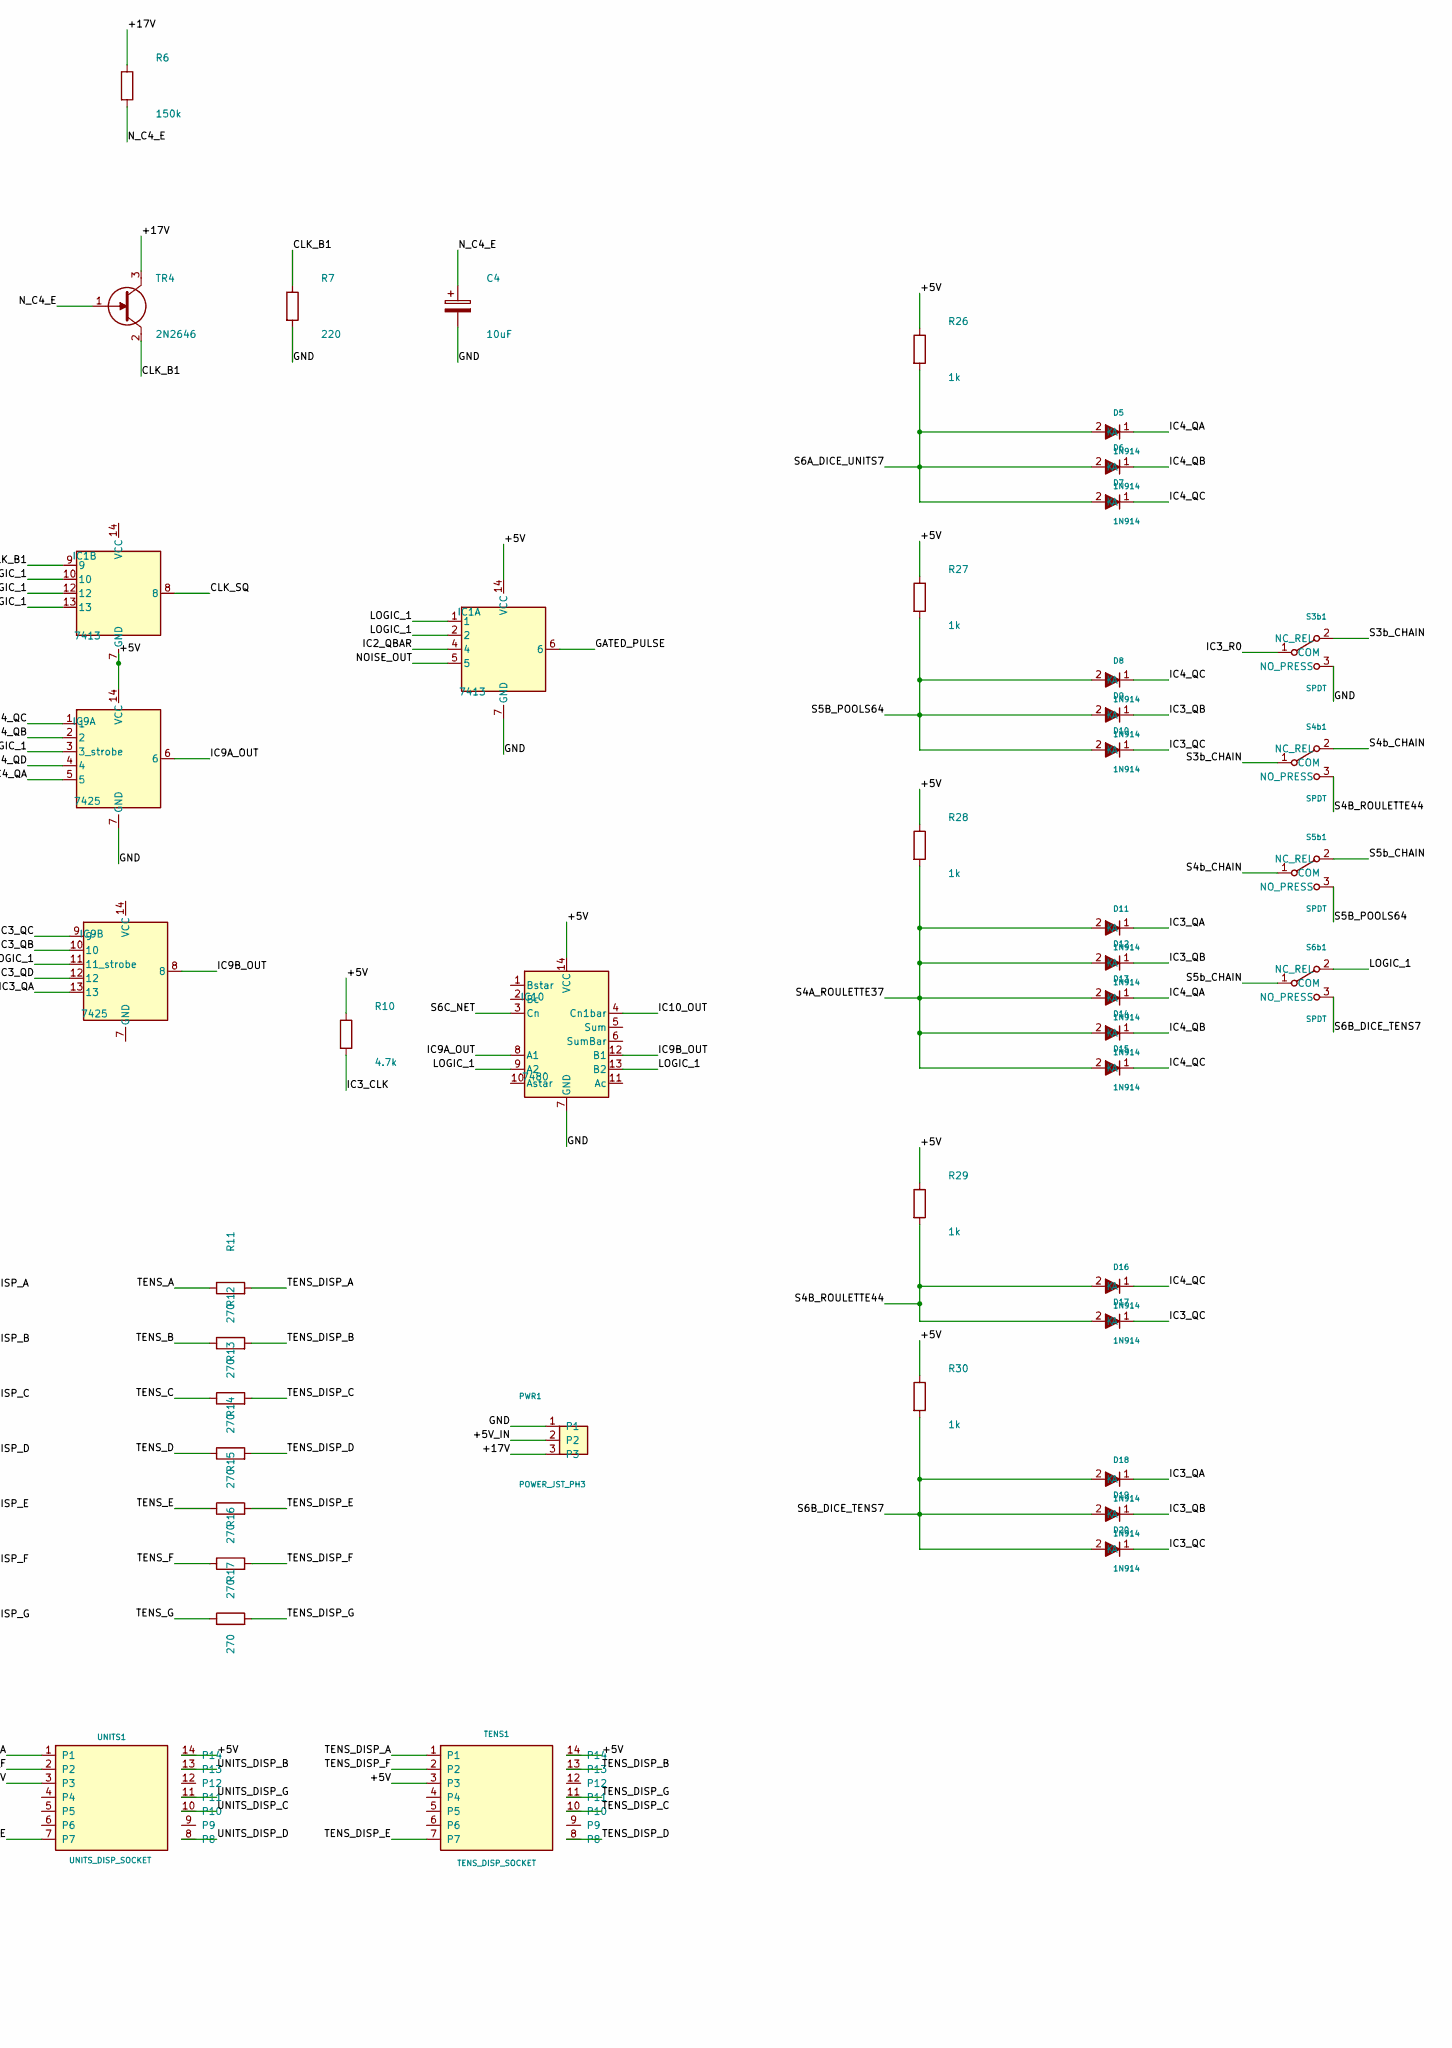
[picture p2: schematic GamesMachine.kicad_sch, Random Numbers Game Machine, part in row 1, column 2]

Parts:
C1, C2, C4: 10uF; CP_Radial_D5.0mm_P2.50mm
C3: 0.1uF; C_Disc_D5.0mm_W2.5mm_P2.50mm
D5, D6, D7, D8, D9, D10, D11, D12, D13, D14, D15, D16, D17, D18, D19, D20: 1N914; D_DO-35_SOD27_P7.62mm_Horizontal
F1: PTC_0.5A; C_Disc_D5.0mm_W2.5mm_P5.00mm
IC1: 7413; DIP-14_W7.62mm
IC2: 7472; DIP-14_W7.62mm
IC3, IC4: 7490; DIP-14_W7.62mm
IC5, IC6: 7447; DIP-16_W7.62mm
IC9: 7425; DIP-14_W7.62mm
IC10: 7480; DIP-14_W7.62mm
IC11: 7412; DIP-14_W7.62mm
PWR1: POWER_JST_PH3; JST_PH_B3B-PH-K_1x03_P2.00mm_Vertical
R1: 47k; R_Axial_DIN0207_L6.3mm_D2.5mm_P10.16mm_Horizontal
R2, R8, R9, R10: 4.7k; R_Axial_DIN0207_L6.3mm_D2.5mm_P10.16mm_Horizontal
R3: 100k; R_Axial_DIN0207_L6.3mm_D2.5mm_P10.16mm_Horizontal
R4, R5: 2.2k; R_Axial_DIN0207_L6.3mm_D2.5mm_P10.16mm_Horizontal
R6: 150k; R_Axial_DIN0207_L6.3mm_D2.5mm_P10.16mm_Horizontal
R7: 220; R_Axial_DIN0207_L6.3mm_D2.5mm_P10.16mm_Horizontal
R11, R12, R13, R14, R15, R16, R17, R18, R19, R20, R21, R22, R23, R24: 270; R_Axial_DIN0207_L6.3mm_D2.5mm_P10.16mm_Horizontal
R25, R26, R27, R28, R29, R30: 1k; R_Axial_DIN0207_L6.3mm_D2.5mm_P10.16mm_Horizontal
S1: SPDT; JST_PH_B2B-PH-K_1x02_P2.00mm_Vertical
S3a1, S3b1, S4a1, S4b1, S5a1, S5b1, S5c1, S6a1, S6b1, S6c1, S6d1: SPDT; JST_PH_B3B-PH-K_1x03_P2.00mm_Vertical
TENS1: TENS_DISP_SOCKET; DIP-14_W7.62mm
TR1, TR2, TR3: 2N2926; TO-92_Inline
TR4: 2N2646; TO-18-3
UNITS1: UNITS_DISP_SOCKET; DIP-14_W7.62mm
Z1: 1N4733A_5.1V; D_DO-41_SOD81_P10.16mm_Horizontal

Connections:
/+5V_IN: F1.1, PWR1.2
/+17V: PWR1.3, R2.1, R4.1, R6.1, TR4.3 (B2)
/CLK_B1: IC1.9, R7.1, TR4.2 (B1)
/CLK_SQ: IC1.8, IC2.12 (CLK)
/GATED_PULSE: IC1.6, IC4.14 (CKA)
/IC2_CLR: IC2.13 (CLR), IC11.6, R8.2, S1.1 (COM)
/IC2_Q: IC2.6 (Q), IC5.4 (BI_RBO), IC6.4 (BI_RBO)
/IC2_QBAR: IC1.4, IC2.8 (QBAR)
/IC3_CLK: IC3.14 (CKA), IC11.12, R10.2
/IC3_QA: D11.1 (K), D18.1 (K), IC3.1 (CKB), IC3.12 (QA), IC5.7 (D), IC9.13
/IC3_QB: D9.1 (K), D12.1 (K), D19.1 (K), IC3.9 (QB), IC5.1 (C), IC9.10
/IC3_QC: D10.1 (K), D17.1 (K), D20.1 (K), IC3.8 (QC), IC5.2 (B), IC9.9
/IC3_QD: IC3.11 (QD), IC5.6 (A), IC9.12
/IC3_R0: IC3.2 (R01), IC3.3 (R02), S3b1.1 (COM)
/IC4_QA: D5.1 (K), D13.1 (K), IC4.1 (CKB), IC4.12 (QA), IC6.7 (D), IC9.5
/IC4_QB: D6.1 (K), D14.1 (K), IC4.9 (QB), IC6.1 (C), IC9.2
/IC4_QC: D7.1 (K), D8.1 (K), D15.1 (K), D16.1 (K), IC4.8 (QC), IC6.2 (B), IC9.1, IC11.13
/IC4_QD: IC4.11 (QD), IC6.6 (A), IC9.4
/IC4_R0: IC4.2 (R01), IC4.3 (R02), S3a1.1 (COM)
/IC9A_OUT: IC9.6, IC10.8 (A1)
/IC9B_OUT: IC9.8, IC10.12 (B1)
/IC10_OUT: IC10.4 (Cn1bar), IC11.9, IC11.10, IC11.11
/IC11A_OUT: IC11.4, IC11.5, IC11.8, R9.2
/LOGIC_1: IC1.1, IC1.2, IC1.10, IC1.12, IC1.13, IC2.2 (PR), IC2.9 (K1), IC2.10 (K2), IC2.11 (K3), IC5.3 (LT), IC5.5 (RBI), IC6.3 (LT), IC6.5 (RBI), IC9.3 (3_strobe), IC9.11 (11_strobe), IC10.9 (A2), IC10.13 (B2), IC11.1, IC11.2, R25.2, S5c1.3 (NO_PRESS), S6a1.2 (NC_REL), S6b1.2 (NC_REL), S6c1.3 (NO_PRESS), S6d1.3 (NO_PRESS)
/NOISE_OUT: C3.2, IC1.5, R5.1
/N_C4_E: C4.1, R6.2, TR4.1 (E)
/N_TR1E: C1.1, R1.2, TR1.1 (E)
/N_TR2C: C2.1, R1.1, R2.2, TR2.2 (C)
/N_TR3B: C2.2, R3.2, TR3.3 (B)
/N_TR3C: C3.1, R3.1, R4.2, TR3.2 (C)
/N_TR12_BASE: TR1.3 (B), TR2.3 (B)
/S3a_CHAIN: S3a1.2 (NC_REL), S4a1.1 (COM)
/S3b_CHAIN: S3b1.2 (NC_REL), S4b1.1 (COM)
/S4A_ROULETTE37: D11.2 (A), D12.2 (A), D13.2 (A), D14.2 (A), D15.2 (A), R28.2, S4a1.3 (NO_PRESS)
/S4B_ROULETTE44: D16.2 (A), D17.2 (A), R29.2, S4b1.3 (NO_PRESS)
/S4a_CHAIN: S4a1.2 (NC_REL), S5a1.1 (COM)
/S4b_CHAIN: S4b1.2 (NC_REL), S5b1.1 (COM)
/S5B_POOLS64: D8.2 (A), D9.2 (A), D10.2 (A), R27.2, S5b1.3 (NO_PRESS)
/S5C_S6D_EN: IC11.3, S5c1.1 (COM)
/S5a_CHAIN: S5a1.2 (NC_REL), S6a1.1 (COM)
/S5b_CHAIN: S5b1.2 (NC_REL), S6b1.1 (COM)
/S5c_CHAIN: S5c1.2 (NC_REL), S6d1.1 (COM)
/S6A_DICE_UNITS7: D5.2 (A), D6.2 (A), D7.2 (A), R26.2, S6a1.3 (NO_PRESS)
/S6B_DICE_TENS7: D18.2 (A), D19.2 (A), D20.2 (A), R30.2, S6b1.3 (NO_PRESS)
/S6C_NET: IC10.3 (Cn), S6c1.1 (COM)
/TENS_A: IC5.13 (a), R11.1
/TENS_B: IC5.12 (b), R12.1
/TENS_C: IC5.11 (c), R13.1
/TENS_D: IC5.10 (d), R14.1
/TENS_DISP_A: R11.2, TENS1.1
/TENS_DISP_B: R12.2, TENS1.13
/TENS_DISP_C: R13.2, TENS1.10
/TENS_DISP_D: R14.2, TENS1.8
/TENS_DISP_E: R15.2, TENS1.7
/TENS_DISP_F: R16.2, TENS1.2
/TENS_DISP_G: R17.2, TENS1.11
/TENS_E: IC5.9 (e), R15.1
/TENS_F: IC5.15 (f), R16.1
/TENS_G: IC5.14 (g), R17.1
/UNITS_A: IC6.13 (a), R18.1
/UNITS_B: IC6.12 (b), R19.1
/UNITS_C: IC6.11 (c), R20.1
/UNITS_D: IC6.10 (d), R21.1
/UNITS_DISP_A: R18.2, UNITS1.1
/UNITS_DISP_B: R19.2, UNITS1.13
/UNITS_DISP_C: R20.2, UNITS1.10
/UNITS_DISP_D: R21.2, UNITS1.8
/UNITS_DISP_E: R22.2, UNITS1.7
/UNITS_DISP_F: R23.2, UNITS1.2
/UNITS_DISP_G: R24.2, UNITS1.11
/UNITS_E: IC6.9 (e), R22.1
/UNITS_F: IC6.15 (f), R23.1
/UNITS_G: IC6.14 (g), R24.1

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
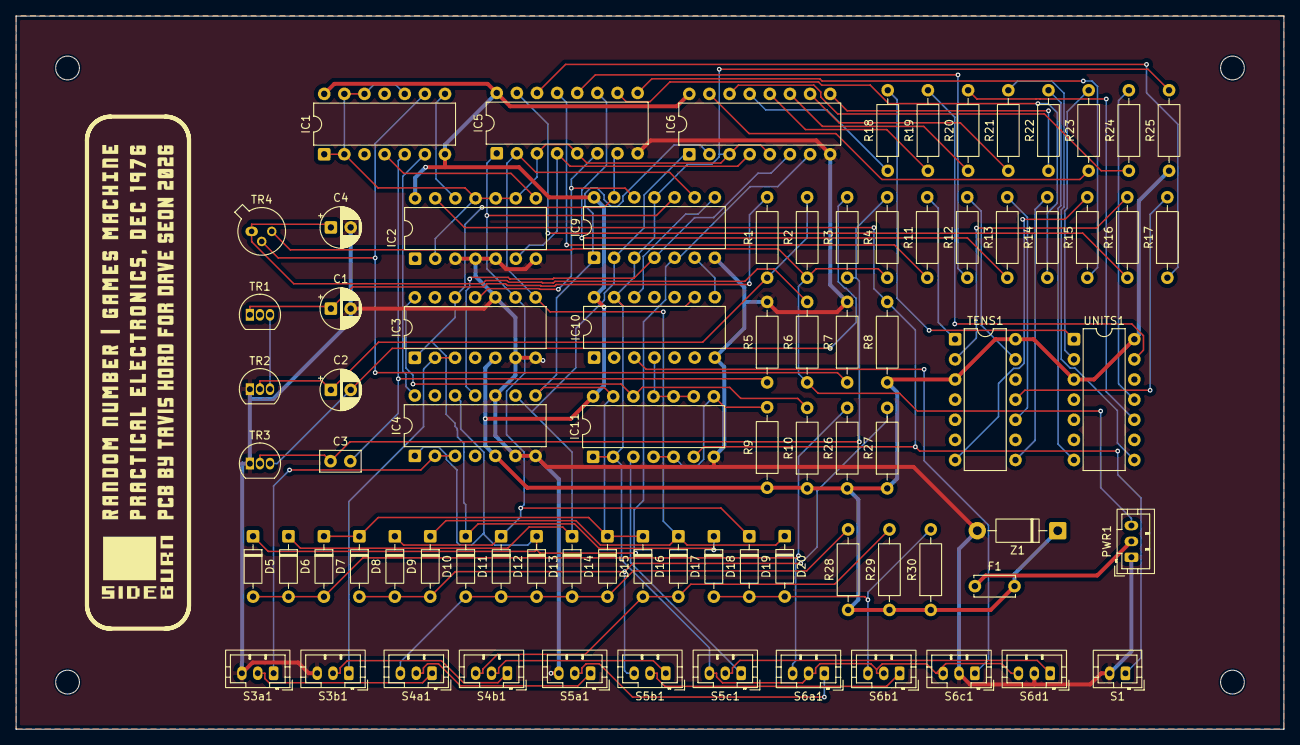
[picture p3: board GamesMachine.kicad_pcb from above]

Board: 2 copper layers, 160.0 x 90.0 mm, 84 parts (0 on the bottom side), 75 nets.

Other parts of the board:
BLMH: MountingHole_3mm
BRMH: MountingHole_3mm
TLMH: MountingHole_3mm
TRMH: MountingHole_3mm

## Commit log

2026-08-17 Initial commit: Games Machine rev 1.0 as fabricated
    Baseline snapshot of the KiCad project as it was ordered and built
    (fabricated 2026-07-09), before any rev 2.0 defect fixes. Includes
    schematic, PCB, custom symbol library, 3D model, and gerbers.
    Known defects to be fixed in follow-up commits, tracked in the
    DavesGamesMachine client project Docs/Rev2_Board_Fixes.md.
    [GamesMachine copy.kicad_sch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]
2026-08-17 Fix: tie LOGIC_0 net to GND (schematic side)
    LOGIC_0 was drawn as its own local net label, never actually connected
    to ground, causing both 7490s to read a floating "1" on their
    reset-to-nine inputs and freeze at 99. Renamed all 12 LOGIC_0 labels
    to GND, merging it with the existing ground net.
    ERC clean of any new conflicts after the change (348 pre-existing
    flags, all off-grid/multi-unit-symbol/NC-pin cosmetic categories
    unrelated to this net).
    PCB side still needs manual attention in Pcbnew: run "Update PCB from
    Schematic" and route/zone-fill whatever connections come up unrouted
    for the former LOGIC_0 pads (IC2 pins 3/4/5, IC3/IC4 pins 6/7,
    S3a/S3b/S5a pin 3, S6c/S6d pin 2) before this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
    [GamesMachine.kicad_sch]
2026-08-17 Apply LOGIC_0 -> GND net merge to PCB
    Ran Update PCB from Schematic in Pcbnew so the board file picks up the
    LOGIC_0 -> GND rename from d471d4e. LOGIC_0 no longer appears anywhere
    in the PCB; the previously floating pads (IC2 pins 3/4/5, IC3 and IC4
    pins 6/7) now sit on /GND.
    Routing and zone fill still need checking in Pcbnew before this is
    fabrication-ready.
    [GamesMachine.kicad_pcb]
2026-08-17 Fix: diode symbol pin numbering to match stock footprint
    The project's cached Device:D symbol had pin 1 = anode, while the
    stock DO-35 footprint correctly places the silkscreen cathode band at
    pad 1. The footprint was never wrong -- only the schematic's cached
    copy of the symbol had drifted from the stock library. Every diode on
    rev 1.0 therefore had to be installed opposite the printed band.
    Swapped the two pin numbers in the cached symbol (A position now 2,
    K position now 1), leaving pin names, graphics and all wiring
    untouched. KiCad binds wires by coordinate rather than pin number, so
    this corrects all 17 diodes (D5-D20 plus Z1, which share this symbol)
    in one edit.
    Verified by netlist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
    [GamesMachine.kicad_sch]
2026-08-17 Rotate all 17 diodes 180 degrees to restore routing geometry
    Follow-on to the diode symbol pin-number fix. After that change the pad
    numbering swapped but the parts stayed put, which inverted the layout:
    the common decode bus landed on the row the individual counter traces
    used to occupy and vice versa, making the area awkward to route.
    Rotating each diode 180 degrees puts pad 1 where pad 2 physically sat,
    so the net at every physical pad location is identical to rev 1.0 again
    and the original routing topology works -- while pad 1, which carries
    the silkscreen cathode band, is now the electrical cathode. That is the
    actual defect being fixed.
    KiCad rotates a footprint about pad 1 rather th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
    [GamesMachine.kicad_pcb]
2026-08-17 Fix: 2N2926 symbol pin order to match the real device (TR1-TR3)
    The project-local 2N2926 symbol declared its pins as E-B-C, but the real
    2N2926 is E-C-B. That mismatch is why TR1, TR2 and TR3 all had to be
    fitted with leads 2 and 3 crossed on the rev 1.0 board.
    Swapped the B and C pin numbers in both the source library and the
    schematic's cached copy of the symbol. Pin names, positions and graphics
    are untouched -- only which pad each pin maps to. Netlist now gives
    pad 1 = E, pad 2 = C, pad 3 = B, so the part drops straight into the
    TO-92 footprint.
    TR4 (2N2646, TO-18) left as is -- confirmed correct as built.
    PCB side pending: Update PCB from Schematic, then re-route TR1-TR3,
    whose pads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
    [GamesMachine.kicad_sch]
2026-08-17 Re-route board after diode pad swap and rotation
    Full re-route in Pcbnew following the diode polarity fix. 793 segments,
    DRC clean: 0 violations, 0 unconnected items.
    [GamesMachine.kicad_pcb]
2026-08-17 Swap UNITS and TENS display positions
    The two displays sat in reverse reading order: UNITS on the left at
    x=149, TENS on the right at x=164, so every result read with its digits
    transposed (the board showed 41 for the value 14). Wiring and silkscreen
    were self-consistent, so this was purely a placement problem -- but it
    masqueraded as a Roulette range failure during bring-up.
    Exchanged the two footprint placements. Both are identical DIP-14
    footprints at the same Y with no rotation, so this is a straight swap of
    their (at ...) positions, and each display keeps its own segment nets.
    Segment resistor banks left in place: R11-R17 and R18-R24 are horizontal
    rows already spanning the full width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
    [GamesMachine.kicad_pcb]
2026-08-17 Re-route display area and TR1-TR3 after placement and pin-order fixes
    Re-routed following the UNITS/TENS display swap and the 2N2926 pin-order
    correction. 789 segments, 0 unconnected items.
    Two starved_thermal errors remain, both on former LOGIC_0 pads that now
    belong to GND (IC3 pad 7 and S5a1 pad 3): each reaches only an isolated
    island of the top-layer pour rather than the main zone. Both pads are
    plated-through and the GND zone is present on both layers, so they are
    very likely still solidly grounded via the bottom zone -- rev 1.0
    shipped with one warning of this same class. Cleanest fixes are a track
    from IC3 pad 7 to IC3 pad 10 (the rev 1.0 bodge wire, in copper) and a
    stitching via b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
    [GamesMachine.kicad_pcb]
2026-08-17 Add stitching vias to clear the two starved thermal warnings
    IC3 pad 7 and S5a1 pad 3 -- both former LOGIC_0 pads now on GND -- each
    reached only an isolated island of the top-layer pour rather than the
    main zone.
    Added a short 0.5 mm stub from each pad to a 0.6/0.3 mm via down to the
    bottom ground zone, matching the board's existing track and via sizes.
    The stub is deliberate: it makes the connection independent of which
    fragment of the pour the via lands in. Nearest non-ground copper is
    about 1 mm from each via.
    DRC now reports 0 violations and 0 unconnected, though the zone fill in
    the file predates the vias -- needs a re-pour in Pcbnew to confirm.
    [GamesMachine.kicad_pcb]
2026-08-17 Refill zones after adding stitching vias
    Zone re-pour in Pcbnew with the new vias in place. DRC confirmed clean:
    0 violations, 0 unconnected items.
    [GamesMachine.kicad_pcb]
2026-08-17 Stop tracking KiCad lock files
    Accidentally committed ~GamesMachine.kicad_pcb.lck in the previous
    commit; these are transient editor locks and do not belong in the repo.
2026-08-17 Regenerate gerbers and drill files for rev 2
    Fab output refreshed from the current board: LOGIC_0 tied to GND, diode
    polarity corrected and diodes rotated, UNITS/TENS displays swapped,
    2N2926 pin order fixed, plus the two stitching vias. Previous contents
    were rev 1.0 output and no longer matched the design.
    Exported with KiCad-style extensions to match the existing filenames,
    X2 format, 6-digit precision; drill files as separate PTH/NPTH Excellon.
    [GamesMachine-B_Cu.gbr, GamesMachine-B_Mask.gbr, GamesMachine-B_Paste.gbr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]
2026-08-17 Close fix 5: TR4 footprint is correct as drawn
    Verified against the 3D view. The pin mapping needs no change -- TR4
    simply wants about 10 degrees of clockwise rotation from the silkscreen
    tab mark when fitting, since the TO-18 leads sit on a circle and don't
    align exactly with the pad angles. A fitting nuance, not a defect.
    Also recorded the sharpie method for identifying UJT leads by
    measurement, since two of the three 2N2646s sourced during rev 1.0
    bring-up turned out to be counterfeit or dead.
2026-08-17 Bring the fix list up to date now that all five are resolved
    Rewrote the running fix list as a record of what was done rather than a
    to-do: every fix is applied on both schematic and PCB, DRC is clean, and
    the fab output has been regenerated.
    F1 moved from 'undersized, size up' to 'leave as is' -- the paper worst
    case is around 580 mA, but the assembled board runs correctly on the
    0.5 A part. Z1 likewise noted as fine in practice, since the 5 V rail
    measures 4.7-4.8 V and the zener never conducts.
2026-08-17 Add parts list and BOM
    Parts list generated from the rev 2.0 schematic, grouped by category with
    the function of each part, plus the off-board items the board BOM cannot
    know about: the two DL707 displays, the interlocked pushbutton bank, and
    the supply that feeds PWR1.
    Includes the sourcing notes that cost the most time on this build -- how
    to test a 2N2646 before fitting it and why a genuine one can still fail,
    the 2N2926's E-C-B pinout, and why the vintage electrolytics (especially
    C1) should be replaced rather than trusted.
    BOM.csv is the raw kicad-cli export for anyone who wants it machine
    readable.
    [BOM.csv]
2026-08-17 Correct the capacitor note: vintage tantalums, not electrolytics
    C1, C2 and C4 in this build were period tantalums supplied with the
    project, not electrolytics, and their failure was specific to that old
    stock rather than something a builder using new parts would hit.
    Reworded so it reads as a caution about reusing vintage parts instead of
    a general warning about the design.
2026-08-17 Drop the capacitor caution from the builder-facing docs
    The leaky C1/C2/C4 were vintage tantalums supplied with this one
    project, so the warning does not generalise to anyone building from new
    parts. Removed from the README and the parts list; the history stays
    recorded in Rev2_Board_Fixes.md.
2026-08-17 Don't assert a capacitor type for the failed C1/C2/C4
    The original parts were supplied with the project and their type was
    never positively identified, so describe them as simply the original
    capacitors.
2026-08-17 Remove the capacitor note from the fix list
    This is a magazine-article project -- everyone sources their own parts,
    so a note about capacitors specific to this one build has no bearing on
    the design and does not belong in the public record.
2026-08-17 Bump title block to rev 2.0
    Schematic and PCB title blocks still read rev 1.0 dated 2026-07-09, the
    fabricated revision. Updated to 2.0 / 2026-08-17 so the drawing sheet
    matches the design.
    [GamesMachine.kicad_pcb, GamesMachine.kicad_sch]
2026-08-17 Warn that the pre-assembly workarounds are rev 1.0 only
    The plan told the builder to fit the LOGIC_0 ground bodge and to fit
    every diode opposite the silkscreen band. Both are correct for rev 1.0
    and wrong for rev 2.0, where the net is tied to GND and the band marks
    the cathode -- following it on a rev 2.0 board would put all 17 diodes
    in backwards.
    Added a revision check at the top and marked the two affected findings.
    Dropped 'rev 1.0' from the header since the staged bring-up procedure
    applies to both revisions.
